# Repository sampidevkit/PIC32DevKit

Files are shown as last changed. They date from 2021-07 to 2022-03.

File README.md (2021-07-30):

# PIC32MM MICROCONTROLLER DEVELOPMENT KIT
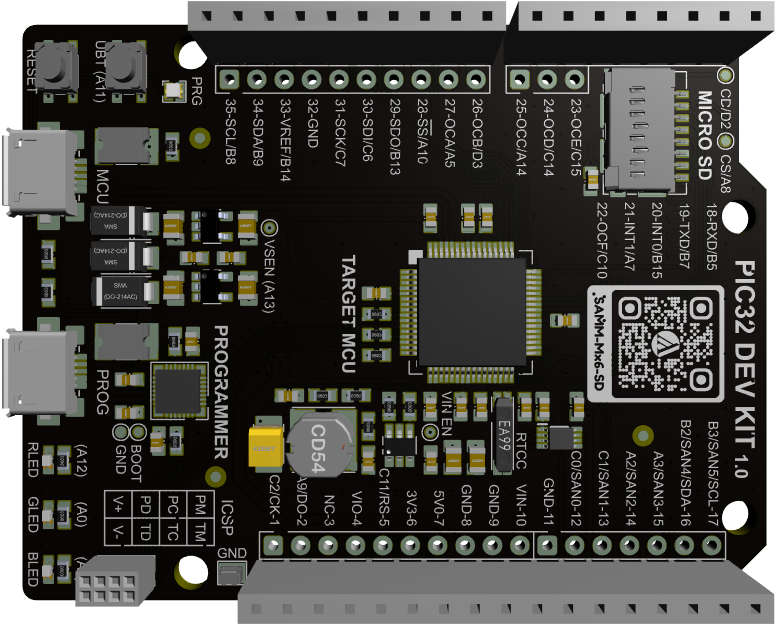
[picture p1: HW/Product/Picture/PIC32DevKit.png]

<br/>Đây là thiết kế mở - một kit phát triển vi điều khiển 32-bit họ PIC32MM. Kit được trang bị các tính năng như sau:<br/>
* PCB và các ngõ vào ra theo định dạng của Arduino Uno.
* Mạch nạp tích hợp theo kiểu USB lưu trữ, tệp hex sẽ được kéo - thả để nạp trực tiếp mà không cần sử dụng phần mềm nạp cũng như các mạch nạp bên ngoài như PICKit, ICD, ..., tuy nhiên người dùng vẫn có thể sử dụng được các mạch nạp chuyên dụng kết nối với cổng ICSP được thiết kế sẵn.
* Cổng chuyển đổi USB - UART, người dùng không cần sử dụng thêm thiết bị chuyển đổi bên ngoài như CP2102, FT232, ...
* Khe cắm thẻ nhớ. Giao tiếp SPI với MCU chính.
* Bộ chuyển đổi logic để giao tiếp với RGB chip LED (APA102, WS2812, SK9822, ...). <br/>
## 1. Sơ Đồ Khối
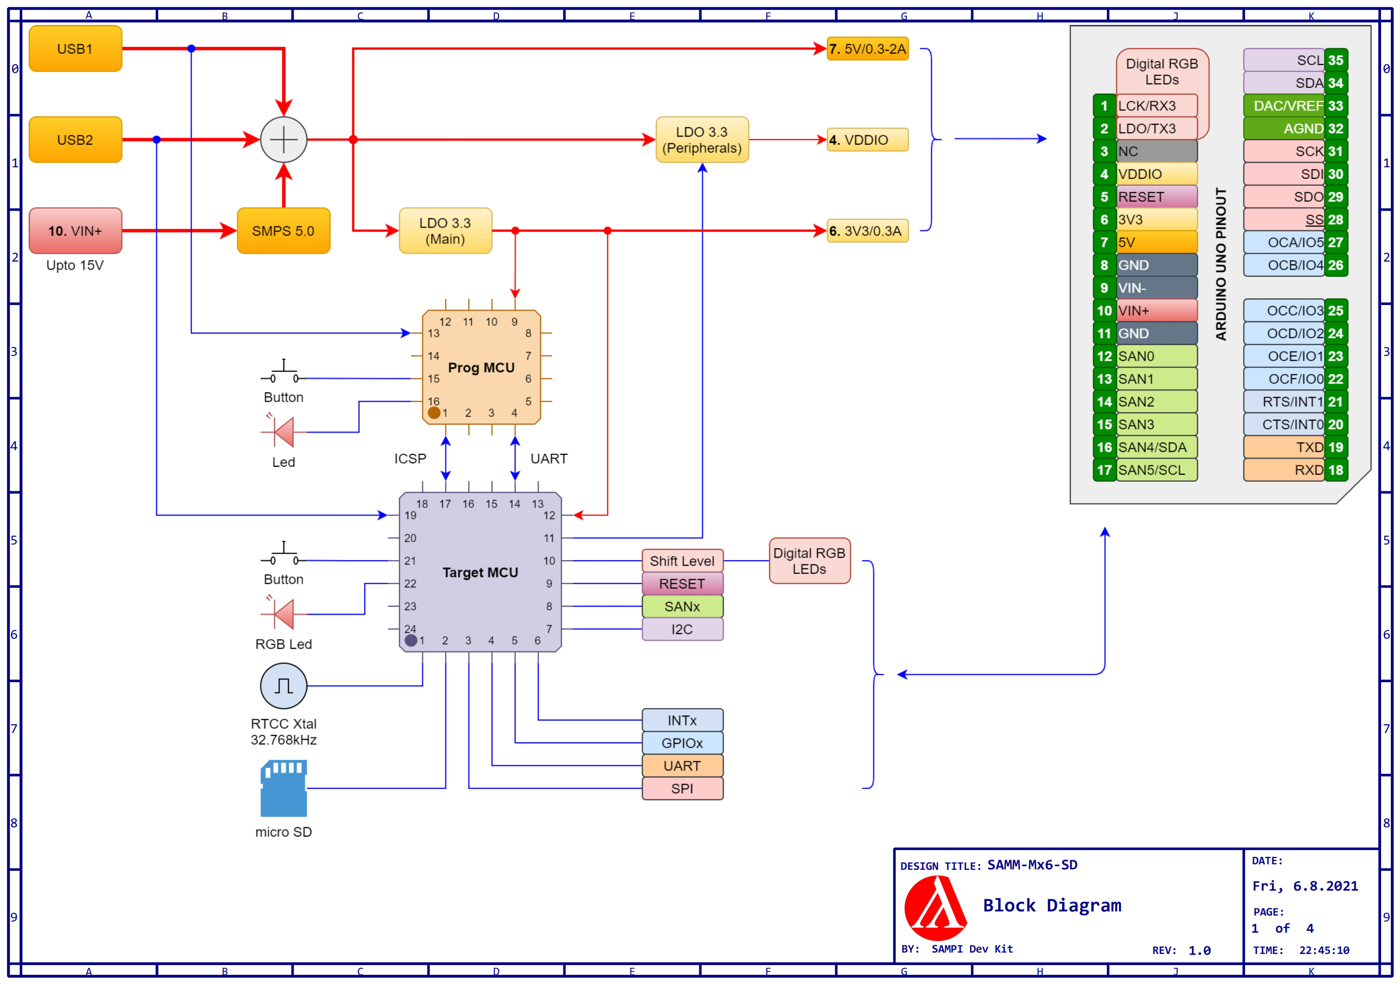
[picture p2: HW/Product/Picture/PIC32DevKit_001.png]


## 2. Sơ Đồ Nguyên Lý
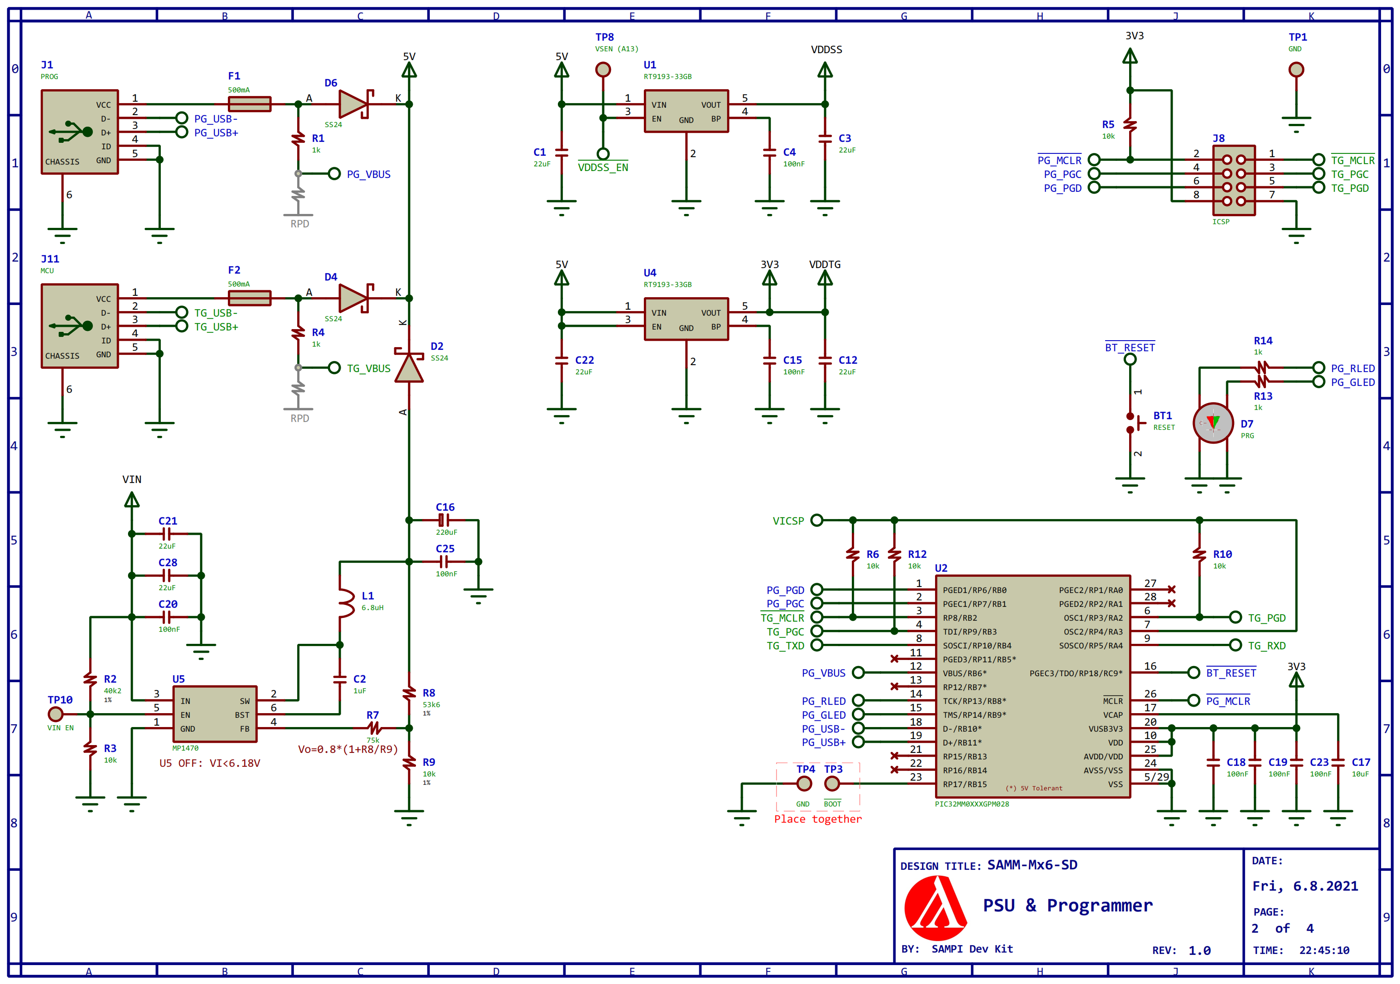
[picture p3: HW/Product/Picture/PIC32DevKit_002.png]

<br/>
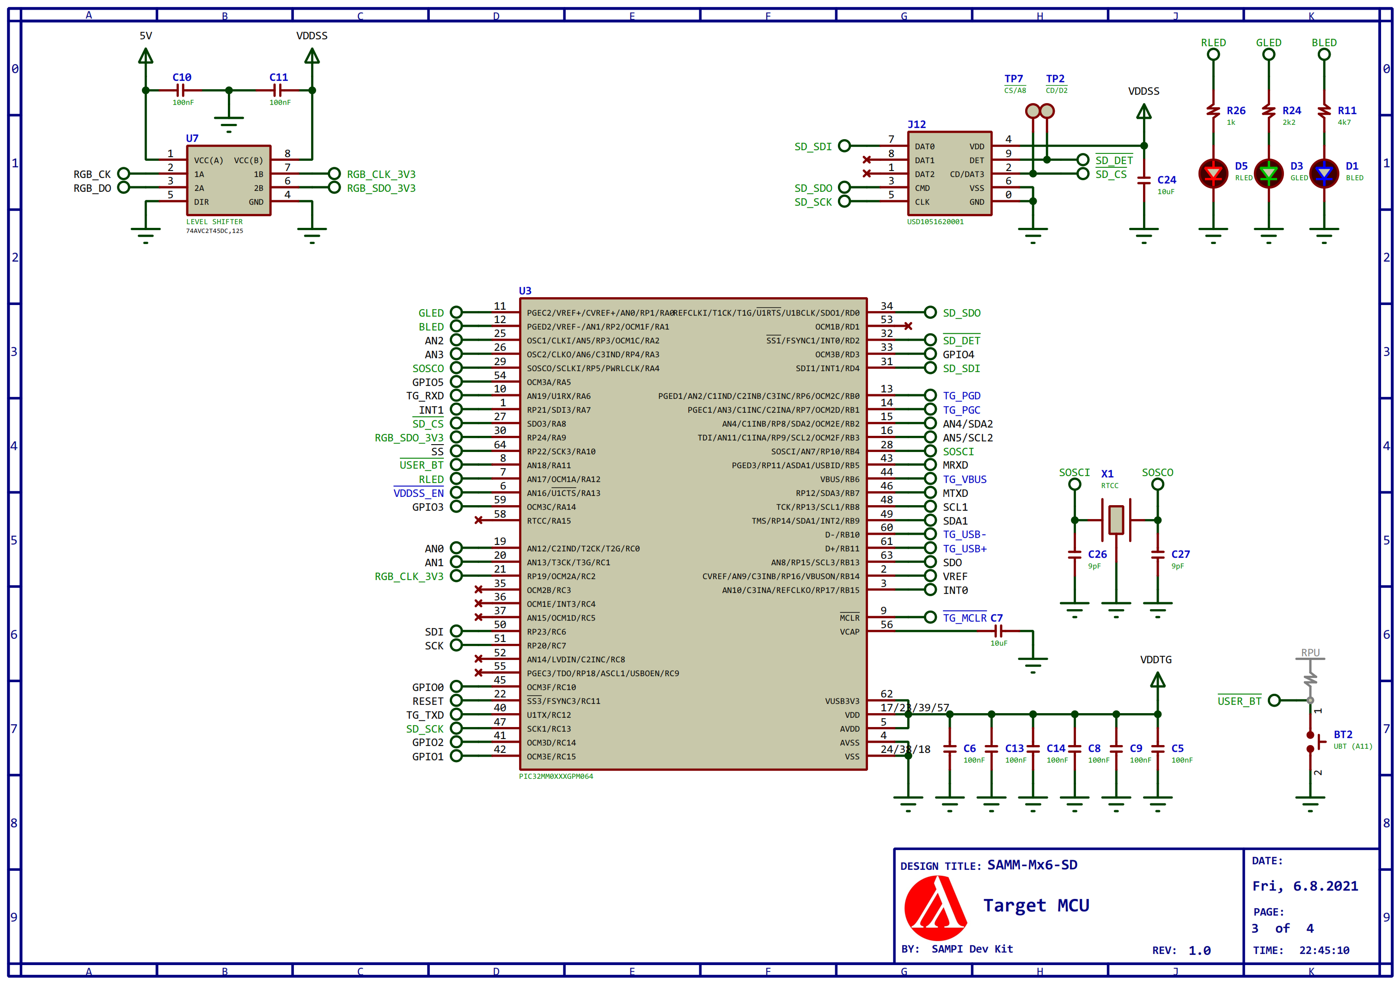
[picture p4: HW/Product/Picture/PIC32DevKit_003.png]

<br/>
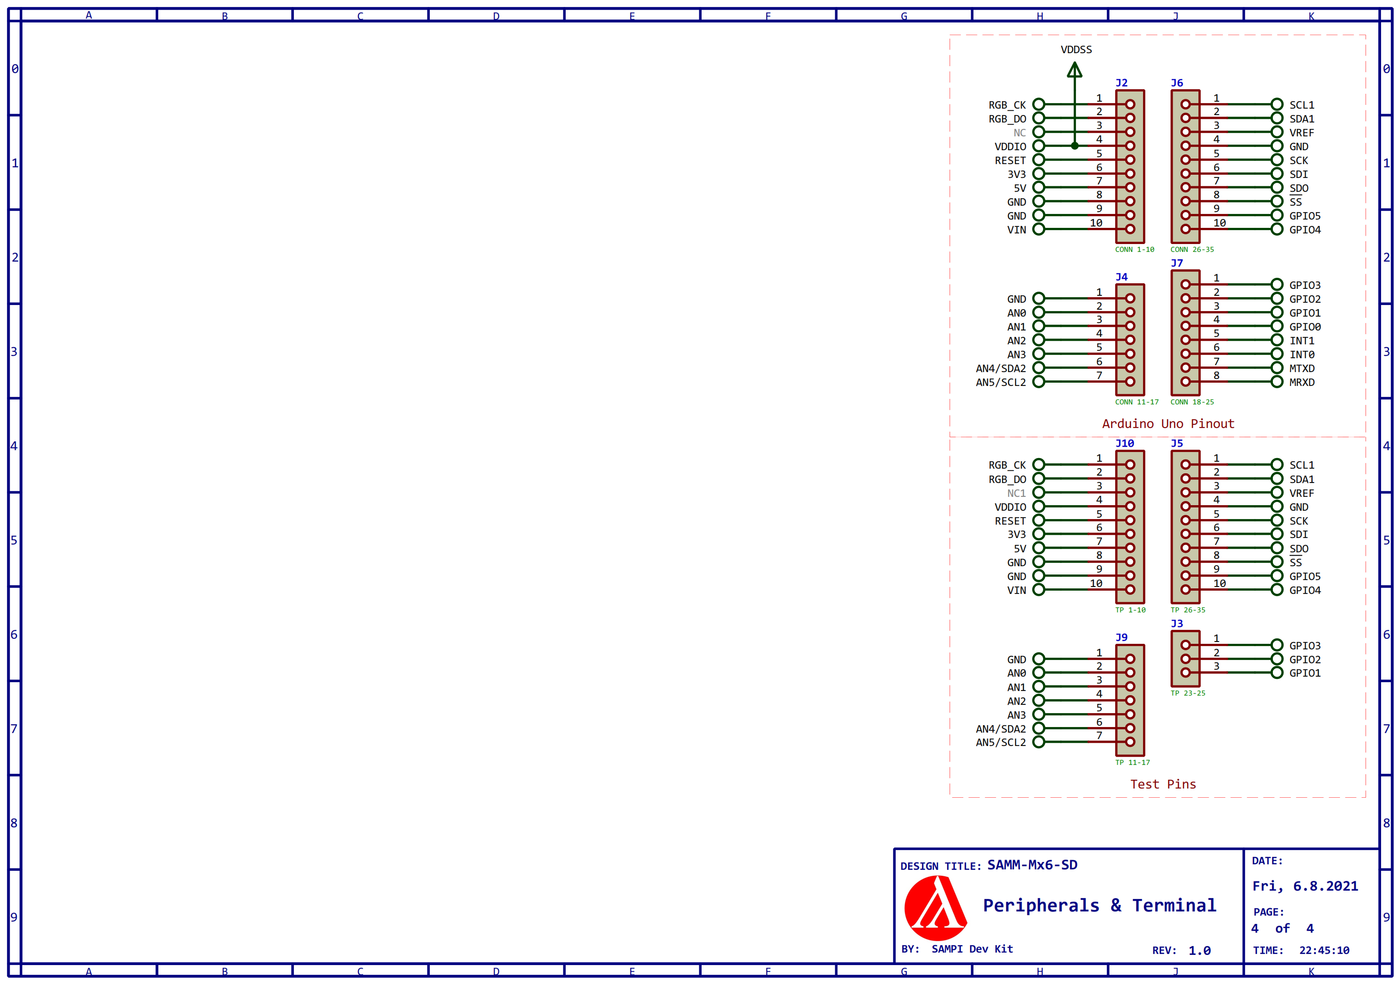
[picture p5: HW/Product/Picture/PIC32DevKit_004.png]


## 3. Vi Điều Khiển Chính PIC32MM0XXXGPM064
Họ vi điều khiển PIC32MM là họ vi điều khiển 32-bit sử dụng core MIPS microAptiv.<br/>
* Dao động nội 8MHz, 32kHz, PLL 96MHz. Tốc độ tối đa 37 DMIPS/25MHz.
* Bộ nhớ chương trình từ 64kByte đến 256kByte, RAM 16byte-32byte.
* Chip được trang bị 3x UART, 3x SPI, 3x I2C, 1x USB OTG.
* PWM chuyên dụng để điều khiển động cơ, 3x timer 16bit hoặc 1x timer 16bit + 1 timer 32bit.
* ADC 10/12 bit, 3x compare.
* Tích hợp module thời gian thực RTCC.
* Ngõ vào ra của các module chức năng có thể cấu hình nhờ chức năng Peripheral Pin Select (PPS).
* Năng lượng thấp, phù hợp cho các ứng dụng sử dụng pin.<br/>
* [Thông tin thêm xem tại đây](https://www.microchip.com/en-us/product/PIC32MM0256GPM064).

## 4. Môi Trường Lập Trình, Trình Biên Dịch và Công Cụ Hỗ Trợ

### 4.1. Môi Trường Lập Trình MPLAB X IDE

Môi trường lập trình MPLAB X IDE sử dụng mã nguồn của Netbeans, giao diện thân thiện và dễ sử dụng. Tải về và hướng dẫn cài đặt tại đây: [Installing MPLAB® X IDE](https://microchipdeveloper.com/mplabx:installation). </br>
Khuyến cáo: Sử dụng Windows 64bit với RAM tối thiểu 4GB và ổ cứng trống từ 20GB.

### 4.2. Trình Biên Dịch MPLAB XC32
Nếu sử dụng ngôn ngữ lập trình C để lập trình cho Kit, bạn cần tải về trình biên dịch XC32. Nó sẽ chuyển mã C thành mã assembly. </br>

</br>Sau đó, nó sẽ chuyển mã assembly sang mã máy dưới dạng file HEX. Bạn cũng có thể sử dụng XC32 để biên dịch cho mã nguồn được viết trực tiếp bằng assembly. 

</br>Trình biên dịch có thể sử dụng miễn phí, không giới hạn code size, chỉ giới hạn các cấp độ tối ưu mã nguồn. Chức năng tối ưu mã nguồn sử dụng trong sản xuất, không cần thiết trong học tập. Tải về và hướng dẫn cài đặt tại đây: [Installing MPLAB® XC32 Compiler](https://microchipdeveloper.com/xc32:installation).

### 4.3. Công Cụ Cấu Hình và Tạo Code Mẫu MPLAB Code Configurator (MCC)
MCC là một plugin của MPLAB X IDE, hỗ trợ tạo cấu hình chip, cấu hình các ngoại vi và các API để người dùng sử dụng mà không mất nhiều thời gian xây dựng chúng. </br>

</br>Tải về và hướng dẫn cài đặt tại đây: [Install MPLAB® Code Configurator (MCC)](https://microchipdeveloper.com/install:mcc).

## 5. Mạch Nạp Tích Hợp

### 5.1. Nạp Chương Trình Mạch Nạp
Chương trình mạch nạp chỉ cần nạp 1 lần. Các công cụ cần chuẩn bị: </br>
* Mạch nạp chuyên dụng như PICkit3, PICkit4, Snap, ICD3, ICD4, ...
* Header đực 2x4x1.27 dùng cho cổng nạp ICSP theo sơ đồ sau: </br>
* Đang cập nhật ...

### 5.2. Cập Nhật Chương Trình Mạch Nạp
Để cập nhật chương trình mới cho chip nạp, bạn có thể thực hiện như mục 5.1 hoặc thực hiện như sau: </br>
* Kết nối kit với máy tính bằng cáp micro USB.
* Nhấn giữ nút RESET đến khi các đèn STT, RLED, BLED cùng sáng (khoảng 5s).
* Vào My Computer/ This PC sẽ thấy xuất hiện ổ đĩa BOOTLOADER.
* Đang cập nhật ...

### 5.3 Các Trạng Thái LED Lỗi
* Lỗi khi ghi file hex vào ổ đĩa của kit: File nạp không đúng định dạng hoặc sự cố kết nối USB.
* Đang cập nhật ...

## 6. Hướng Dẫn Lập Trình Cơ Bản
Đang cập nhật ...

## 7. Tài Liệu Kỹ Thuật:
Đang cập nhật ...

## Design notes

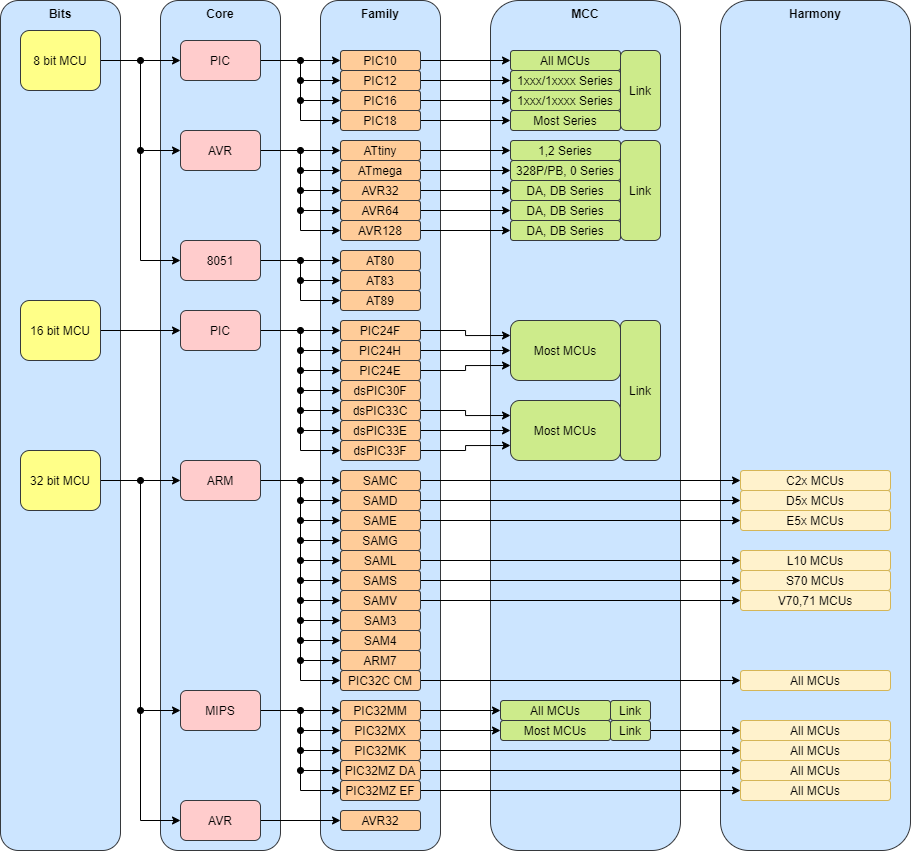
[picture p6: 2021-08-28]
Docs/MICROCHIP_MCU_Overview.png

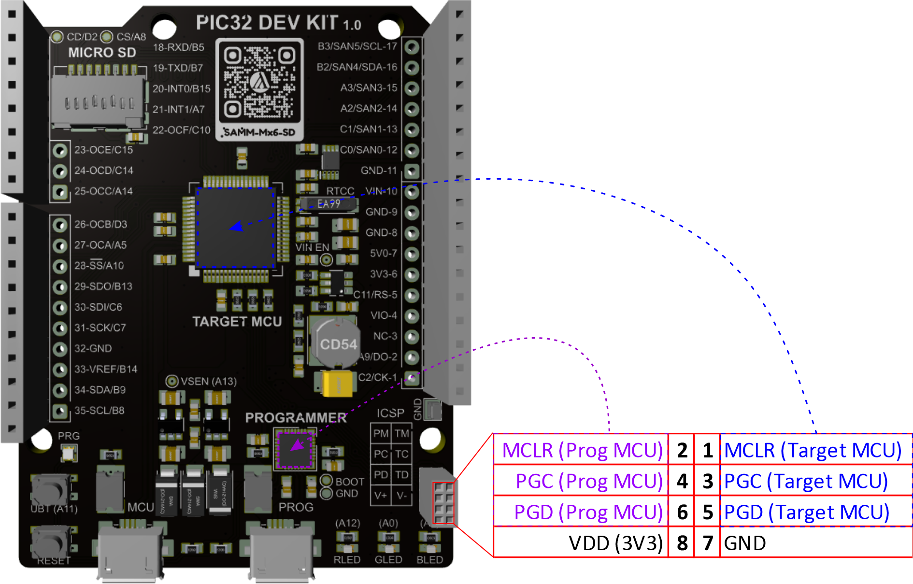
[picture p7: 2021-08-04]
Docs/ICSP.png

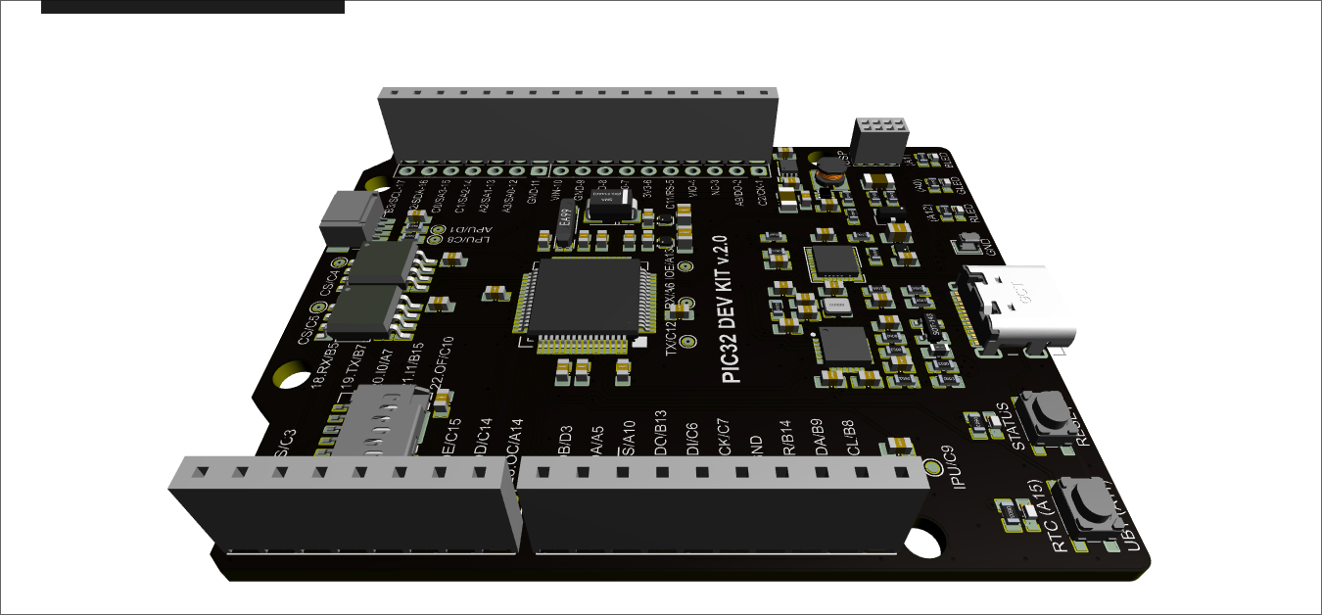
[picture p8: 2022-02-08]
HW/Product/V2.0/Picture/ScreenShot_20220208212421.png

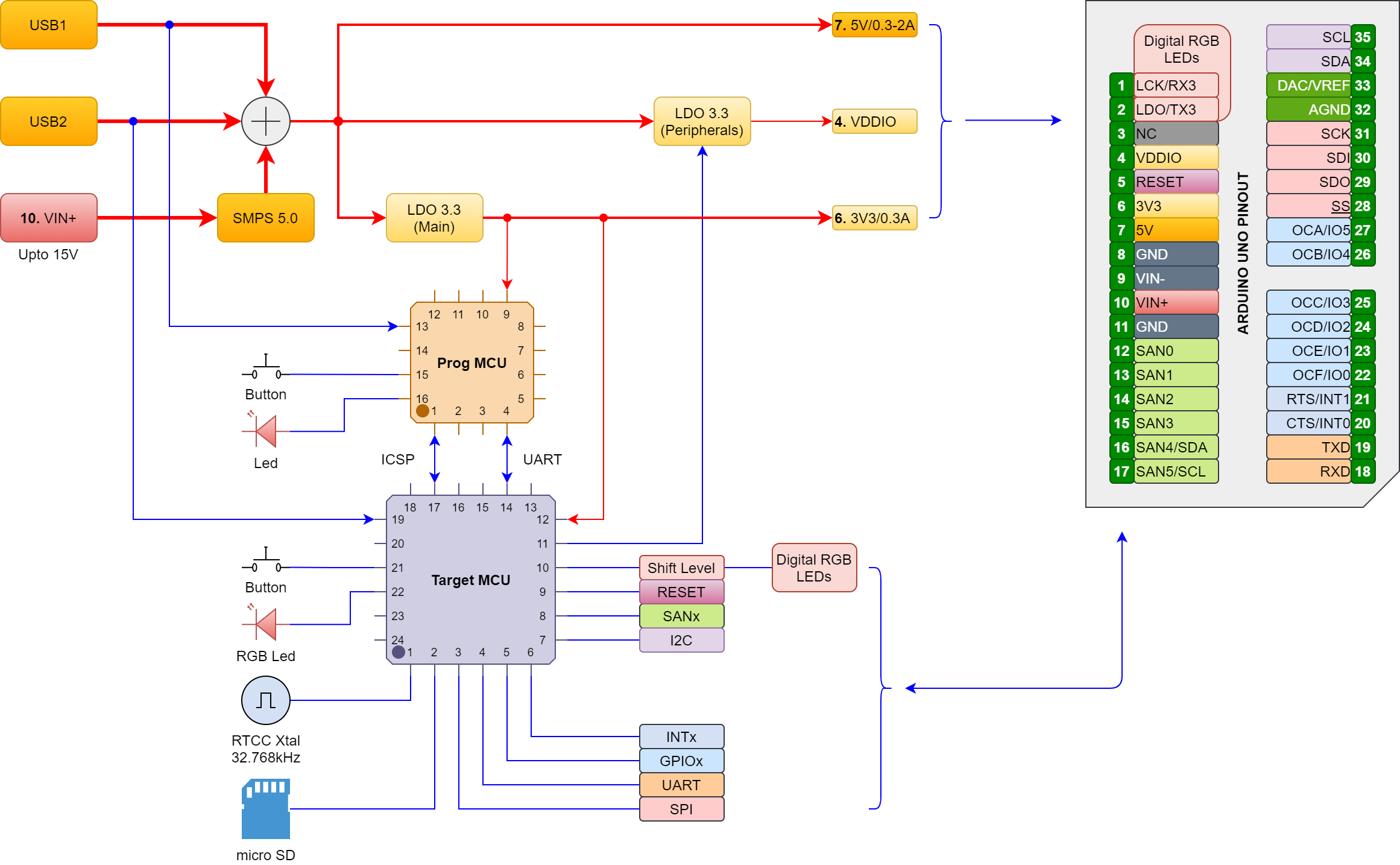
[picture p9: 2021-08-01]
Docs/Diagram.png

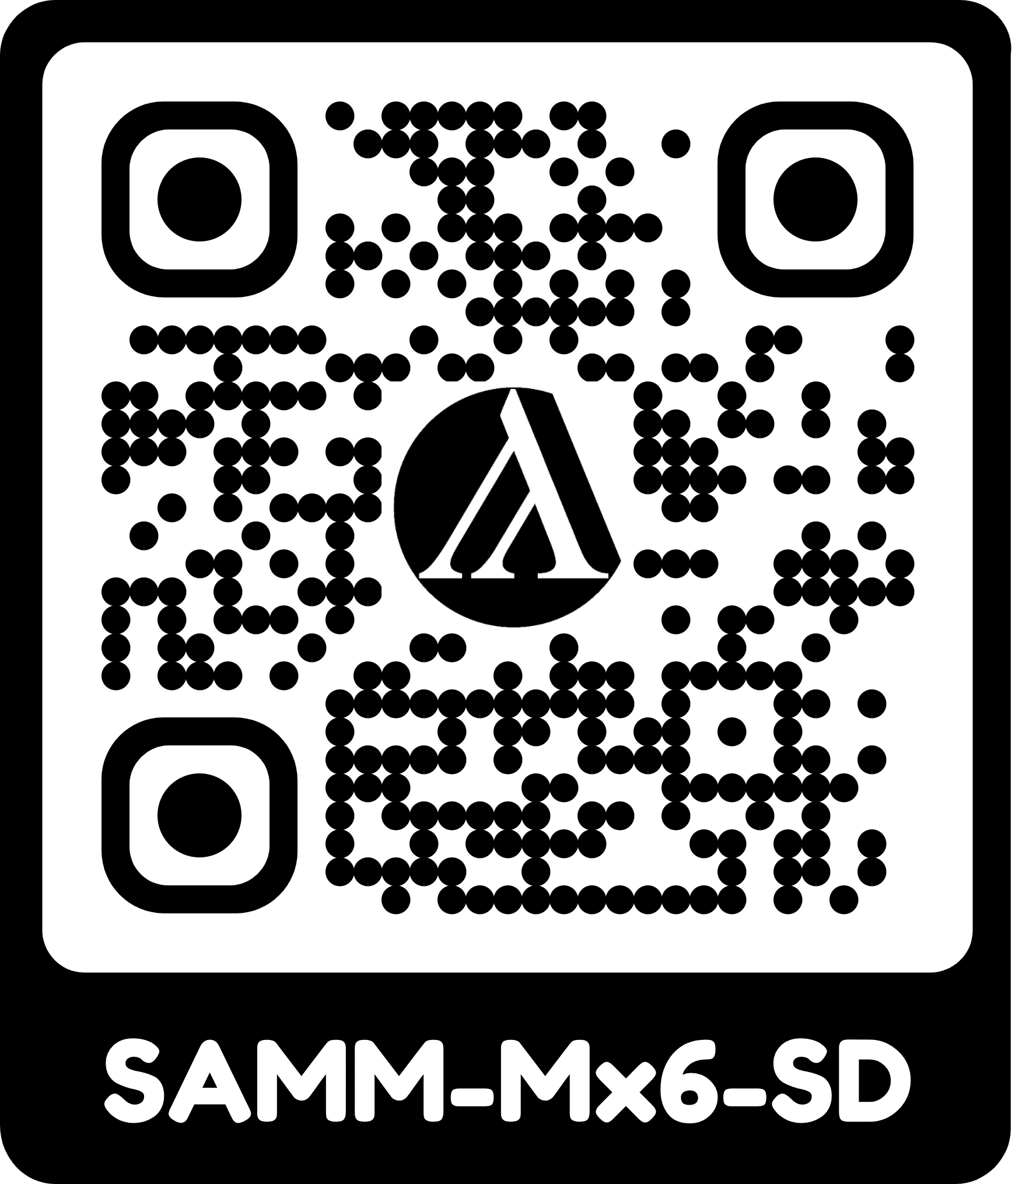
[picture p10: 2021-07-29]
Docs/bit.ly_2TLaNEk.png

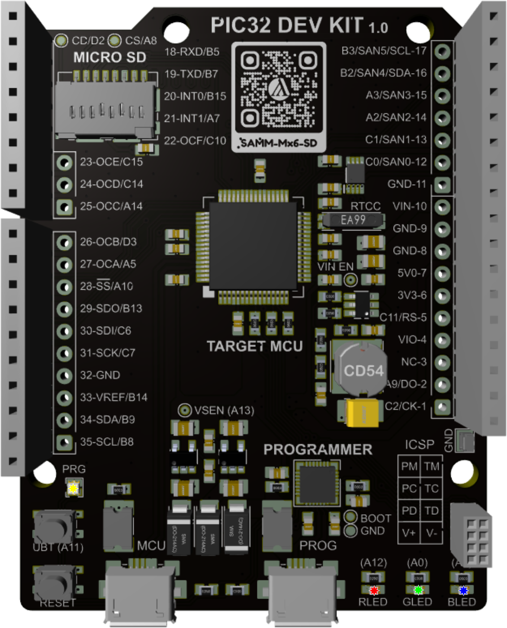
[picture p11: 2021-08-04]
Docs/SAMM-Mx6-SD.png

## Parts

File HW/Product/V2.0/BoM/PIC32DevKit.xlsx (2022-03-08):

No | Part Number | Manufacture | Description | Stock Link | References | Quantity | Unit Cost | Sub Cost
1 | CL10A106MQ8NNNC | Samsung | CAP CER 10UF 6.3V X5R 0603 | https://www.thegioiic.com/products/tu-gom-0603-10uf-25v | C1, C7, C17, C20, C22, C24, C29, C38 | 8 | VND 880 | VND 7040
2 | CL10B104KB8NNWC | Samsung | CAP CER 0.1UF 50V X7R 0603 | https://www.thegioiic.com/products/tu-gom-0603-100nf-0-1uf-50v | C2, C3, C5, C6, C8, C9, C10, C11, C13, C14, C18, C19, C23, C25, C28, C30, C31, C32, C35, C36, C37 | 21 | VND 207 | VND 4347
3 | CL31A226MOCLNNC | Samsung | CAP CER 22UF 16V X5R 1206 | https://www.thegioiic.com/products/tu-gom-0805-22uf-16v | C4, C21 | 2 | VND 1120 | VND 2240
4 | CL21A226MQQNNNG | Samsung | CAP CER 22UF 6.3V X5R 0805 | https://www.thegioiic.com/products/tu-gom-0805-22uf-16v | C12, C15, C16 | 3 | VND 1120 | VND 3360
5 | 0603N100J500CT | Walsin | CAP CER 10PF 50V C0G/NP0 0603 | https://www.thegioiic.com/products/tu-gom-0603-10pf-50v | C26, C27, C33, C34 | 4 | VND 207 | VND 828
6 | RC0603FR-075K1L | Yageo | RES 5.1K OHM 1% 1/10W 0603 | https://www.thegioiic.com/products/dien-tro-51-kohm-0603-1 | R1, R8, R16, R22 | 4 |  | VND 0
7 | RC0603JR-131KL | Yageo | RES 1K OHM 5% 1/10W 0603 | https://www.thegioiic.com/products/dien-tro-1-kohm-0603-5 | R2, R13, R26 | 3 |  | VND 0
8 | RC0603FR-0753K6L | Yageo | RES 53.6K OHM 1% 1/10W 0603 | https://www.thegioiic.com/products/dien-tro-53-6-kohm-0603-1 | R3, R15 | 2 |  | VND 0
9 | AC0603FR-0710KL | Yageo | RES 10K OHM 1% 1/10W 0603 | https://www.thegioiic.com/products/dien-tro-10-kohm-0603-1- | R4, R5, R6, R9, R10, R12, R18, R19, R20, R21 | 10 |  | VND 0
10 | RC0603JR-072K2L | Yageo | RES 2.2K OHM 5% 1/10W 0603 | https://www.thegioiic.com/products/dien-tro-2-2-kohm-0603-5 | R7, R14, R23, R24, R25 | 5 |  | VND 0
11 | RC0603JR-074K7L | Yageo | RES 4.7K OHM 5% 1/10W 060 | https://www.thegioiic.com/products/dien-tro-4-7-kohm-0603-5 | R11 | 1 |  | VND 0
13 | RC0603FR-0712KL | Yageo | RES 12K OHM 1% 1/10W 0603 | https://www.thegioiic.com/products/dien-tro-12-kohm-0603-1- | R17 | 1 |  | VND 0
14 | AP62201Z6-7 | Diodes | DCDC CONV HV BUCK SOT563 T&R 3K | https://www.digikey.com/en/products/detail/diodes-incorporated/AP62201Z6-7/13161377 | U1 | 1 |  | VND 0
15 | PIC32MM0064GPM028-I/M6 | Microchip | IC MCU 32BIT 64KB FLASH 28UQFN | https://www.digikey.com/en/products/detail/microchip-technology/PIC32MM0064GPM028-I-M6/8037777 | U2 | 1 |  | VND 0
16 | PIC32MM0256GPM064T-I/PT | Microchip | IC MCU 32BIT 256KB FLASH 64TQFP | https://www.digikey.com/en/products/detail/microchip-technology/PIC32MM0256GPM064T-I-PT/7354645 | U3 | 1 |  | VND 0
17 | DRTR5V0U2SR-7 | Diodes | TVS DIODE 5.5VWM SOT143 | https://www.digikey.com/en/products/detail/diodes-incorporated/DRTR5V0U2SR-7/4402528 | U4 | 1 |  | VND 0
18 | MIC5528-3.3YMX-TR | Microchip | IC REG LINEAR 3.3V 500MA 6XTDFN | https://www.digikey.com/en/products/detail/microchip-technology/MIC5528-3-3YMX-TR/4465358 | U5, U8, U9 | 3 |  | VND 0
19 | USB2422/MJ | Microchip | IC HUB CTLR USB 2.0 24QFN | https://www.digikey.com/en/products/detail/microchip-technology/USB2422-MJ/4080182 | U6 | 1 |  | VND 0
20 | 74AVC2T45DC,125 | Nexperia | IC TRNSLTR BIDIRECTIONAL 8VSSOP | https://www.digikey.com/en/products/detail/nexperia-usa-inc/74AVC2T45DC-125/1692558 | U7 | 1 |  | VND 0
21 | SST25PF080B-80-4C-SAE-T | Microchip | IC FLASH 8MBIT SPI 80MHZ 8SOIC | https://www.digikey.com/en/products/detail/microchip-technology/SST25PF080B-80-4C-SAE-T/3908714 | U10 | 1 |  | VND 0
22 | 25AA160D-I/SN | Microchip | IC EEPROM 16KBIT SPI 10MHZ 8SOIC | https://www.digikey.com/en/products/detail/microchip-technology/25AA160D-I-SN/2125494 | U11 | 1 |  | VND 0
23 | RZF013P01TL | Microchip | MOSFET P-CH 12V 1.3A TUMT3 | https://www.digikey.com/en/products/detail/rohm-semiconductor/RZF013P01TL/5042831 | Q1 | 1 |  | VND 0
24 |  |  | SML-D12U8W, BLED |  | D1 | 1 |  | VND 0
25 |  |  | SML-D12U8W, RTC (A15) |  | D2, D5 | 2 |  | VND 0
26 |  |  | SML-D12U8W, GLED |  | D3 | 1 |  | VND 0
27 |  |  | SML-D12U8W, STATUS |  | D4 | 1 |  | VND 0
28 |  |  | DO214AC, SS24 |  | D6 | 1 |  | VND 0
29 |  |  | PTS815, RESET |  | BT1, BT2 | 2 |  | VND 0
30 |  |  | 0603_FE, 100R@100MHz |  | FT1 | 1 |  | VND 0
31 |  |  | GCT_USB4105, USB2 |  | J1 | 1 |  | VND 0
32 |  |  | CONN-SIL10, CONN 1-10 |  | J2, J6 | 2 |  | VND 0
33 |  |  | CONN-SIL7, CONN 11-17 |  | J4 | 1 |  | VND 0
34 |  |  | CONN-SIL8, CONN 18-25 |  | J7 | 1 |  | VND 0
35 |  |  | ISP8, ICSP |  | J8 | 1 |  | VND 0
36 |  |  | QWIIC, Qwiic |  | J11 | 1 |  | VND 0
37 |  |  | USD1051620001, USD1051620001 |  | J12 | 1 |  | VND 0
38 |  |  | IND_CD32, 4.7uH |  | L1 | 1 |  | VND 0
39 |  |  | SMD4_7015, RTCC |  | X1 | 1 |  | VND 0
40 |  |  | SMD4_2.5X2.0, 24MHz |  | X2 | 1 |  | VND 0
 |  |  |  |  |  | 96 | VND 185.5729167 | VND 17815

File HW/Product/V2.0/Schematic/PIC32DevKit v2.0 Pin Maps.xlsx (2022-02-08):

Pin | Port | Post | Name | Function | Direction | Init State
1 | A | 7 | INT0 | EXT_INT4 | INPUT | PULL UP
6 | A | 13 | VDDSS_EN | GPIO | OUTPUT | LOW
7 | A | 12 | RLED | GPIO | OUTPUT | LOW
8 | A | 11 | USER_BT_N | GPIO | INPUT | PULL UP
10 | A | 6 | TG_RXD | U1RX | INPUT | PULL UP
11 | A | 0 | GLED | GPIO | OUTPUT | LOW
12 | A | 1 | BLED | GPIO | OUTPUT | LOW
25 | A | 2 | AN1 | AN5 | INPUT | ANALOG
26 | A | 3 | AN0 | AN6 | INPUT | ANALOG
27 | A | 8 | RA8 | RFU | X | X
29 | A | 4 | SOSCO | SOSCO | OUTPUT | LOW
30 | A | 9 | RGB_SDO_3V3 | CLC2OUT | OUTPUT | LOW
54 | A | 5 | GPIO5/OA | OCM3A | OUTPUT | LOW
58 | A | 15 | RTCC_LED | RTCC | OUTPUT | LOW
59 | A | 14 | GPIO3/OC | OCM3C | OUTPUT | LOW
64 | A | 10 | SS_N | GPIO | OUTPUT | HIGH
2 | B | 14 | VREF | CVREF | OUTPUT | ANALOG
3 | B | 15 | INT1 | IOC | INPUT | PULL UP
13 | B | 0 | TG_PGD | GPIO | INPUT | PULL UP
14 | B | 1 | TG_PGC | GPIO | INPUT | PULL UP
15 | B | 2 | AN4/SDA2 | SDA2 | INPUT | LOW
16 | B | 3 | AN5/SCL2 | SCL2 | INPUT | LOW
28 | B | 4 | SOSCI | SOSCI | INPUT | LOW
43 | B | 5 | MRXD | U2RX | INPUT | PULL UP
44 | B | 6 | TG_VBUS | VBUS | INPUT | PULL DOWN
46 | B | 7 | MTXD | U2TX | OUTPUT | HIGH
48 | B | 8 | SCL1 | SCL1 | INPUT | LOW
49 | B | 9 | SDA1 | SDA1 | INPUT | LOW
60 | B | 10 | TG_USB- | D- | INPUT | LOW
61 | B | 11 | TG_USB+ | D+ | INPUT | LOW
63 | B | 13 | SDO | SDO2 | OUTPUT | LOW
19 | C | 0 | AN3 | AN12 | INPUT | ANALOG
20 | C | 1 | AN2 | AN13 | INPUT | ANALOG
21 | C | 2 | RGB_CLK_3V3 | CLC1OUT | OUTPUT | LOW
22 | C | 11 | RESET | GPIO | OUTPUT | LOW
35 | C | 3 | EE_CS_N | GPIO | OUTPUT | HIGH
36 | C | 4 | FL_CS_N | GPIO | OUTPUT | HIGH
37 | C | 5 | SD_CS_N | GPIO | OUTPUT | HIGH
40 | C | 12 | TG_TXD | U1TX | OUTPUT | HIGH
41 | C | 14 | GPIO2/OD | OCM3D | OUTPUT | LOW
42 | C | 15 | GPIO1/OE | OCM3E | OUTPUT | LOW
45 | C | 10 | GPIO0/OF | OCM3F | OUTPUT | LOW
47 | C | 13 | MEM_SCK | SCK1 | OUTPUT | LOW
50 | C | 6 | SDI | SDI2 | INPUT | LOW
51 | C | 7 | SCK | SCK2 | OUTPUT | LOW
52 | C | 8 | LPU_C8 | GPIO | OUTPUT | LOW
55 | C | 9 | IPU_C9 | GPIO | OUTPUT | LOW
31 | D | 4 | MEM_SDI | SDI1 | INPUT | LOW
32 | D | 2 | SD_DET_N | GPIO | INPUT | PULLUP
33 | D | 3 | GPIO4/OB | OCM3B | OUTPUT | LOW
34 | D | 0 | MEM_SDO | SDO1 | OUTPUT | LOW
53 | D | 1 | APU_D1 | GPIO | OUTPUT | LOW
4 | P | P | AVSS | GND | X | X
5 | P | P | AVDD | 3V3 | X | X
9 | P | P | MCLR_N | MCLR | X | X
17 | P | P | VDD | 3V3 | X | X
18 | P | P | VSS | GND | X | X
23 | P | P | VDD | 3V3 | X | X
24 | P | P | VSS | GND | X | X
38 | P | P | VSS | GND | X | X
39 | P | P | VDD | 3V3 | X | X
56 | P | P | VCAP | VCAP | X | X
57 | P | P | VDD | 3V3 | X | X
62 | P | P | VUSB3V3 | 3V3 | X | X

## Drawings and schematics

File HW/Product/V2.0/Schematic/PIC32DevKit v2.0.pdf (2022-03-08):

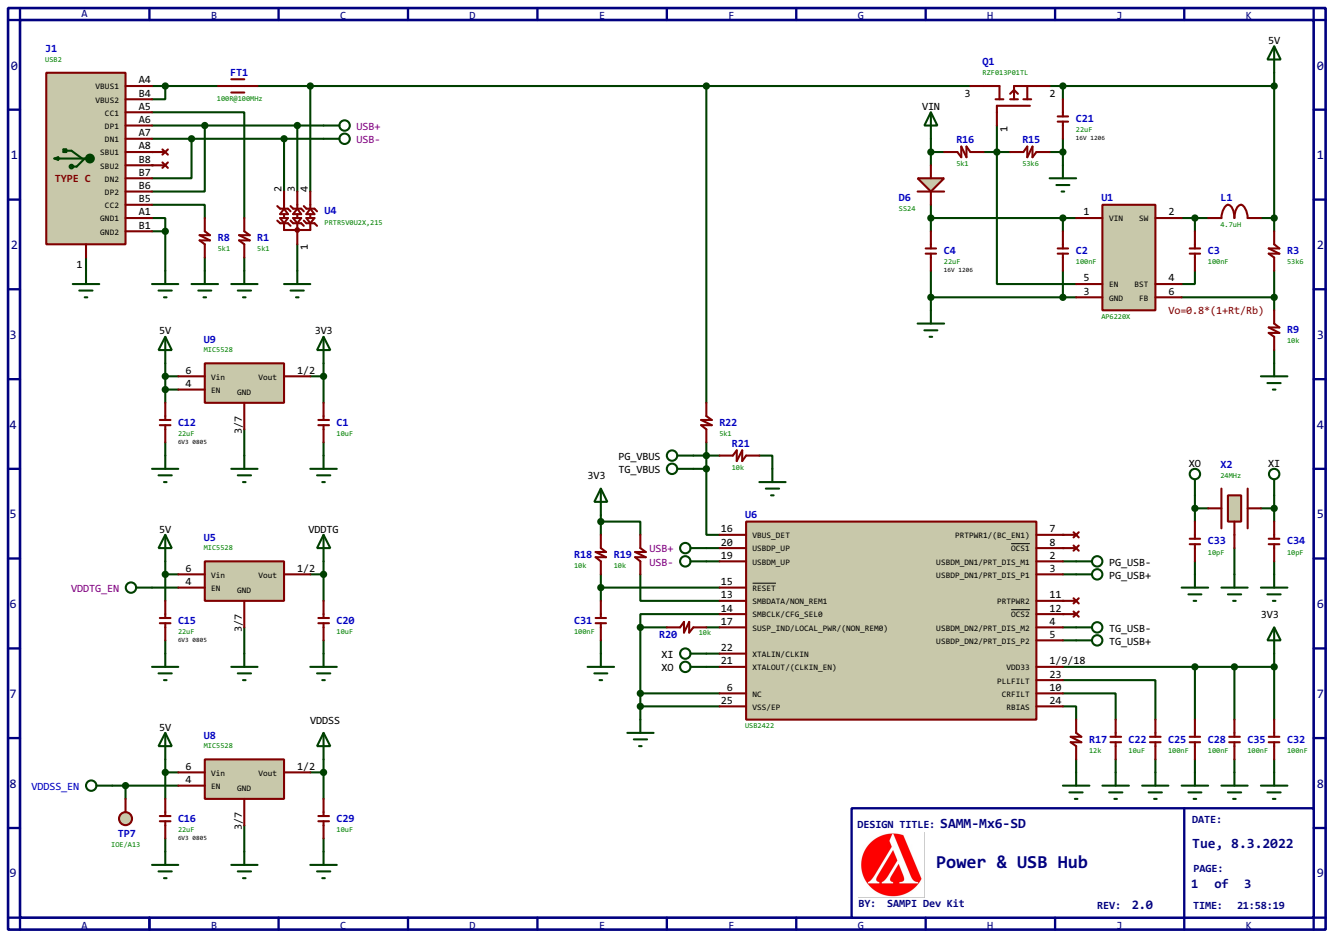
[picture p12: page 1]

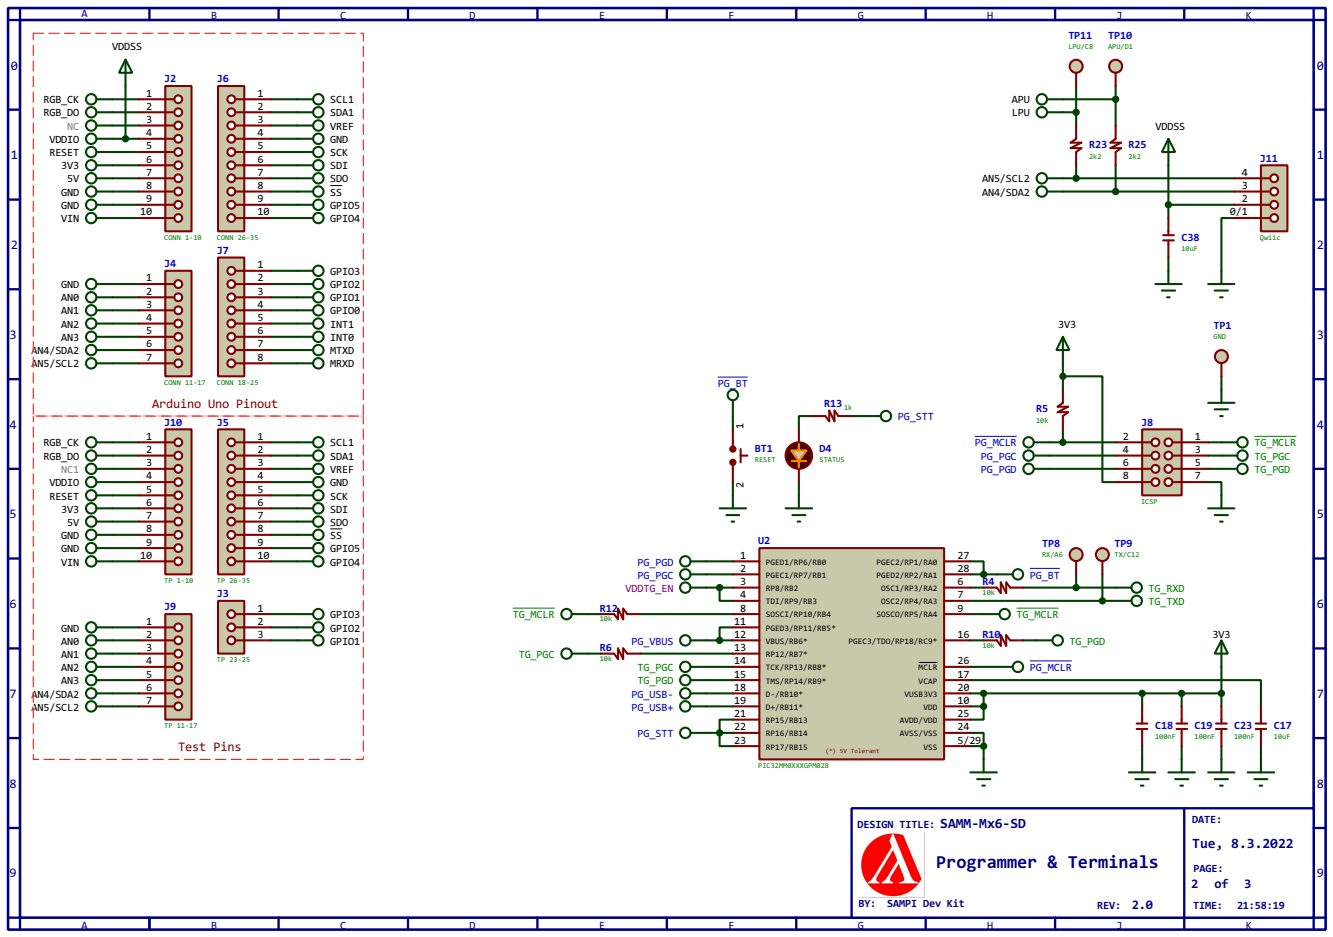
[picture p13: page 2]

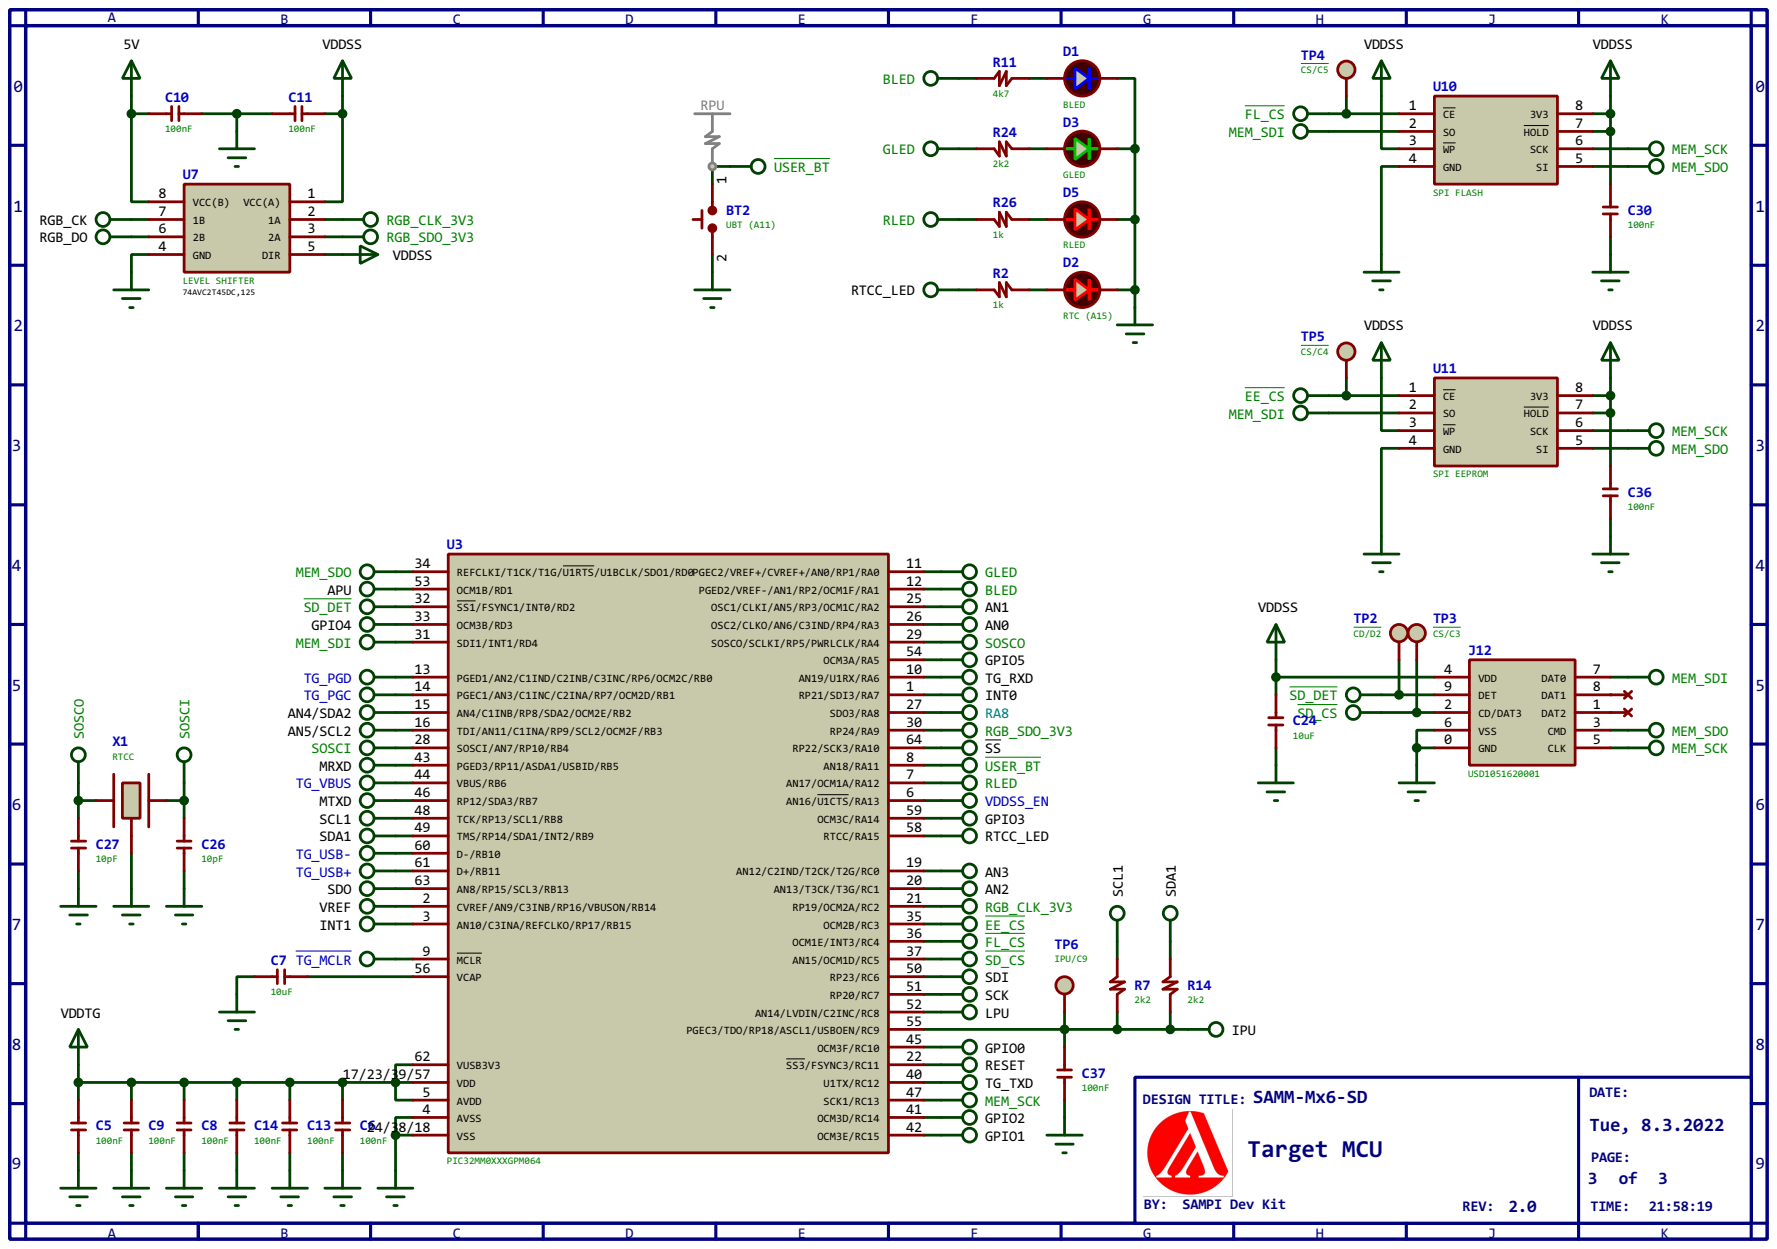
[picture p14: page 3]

VDD 17/23/39/57

AVDD 5

DESIGN TITLE: SAMM-Mx6-SD

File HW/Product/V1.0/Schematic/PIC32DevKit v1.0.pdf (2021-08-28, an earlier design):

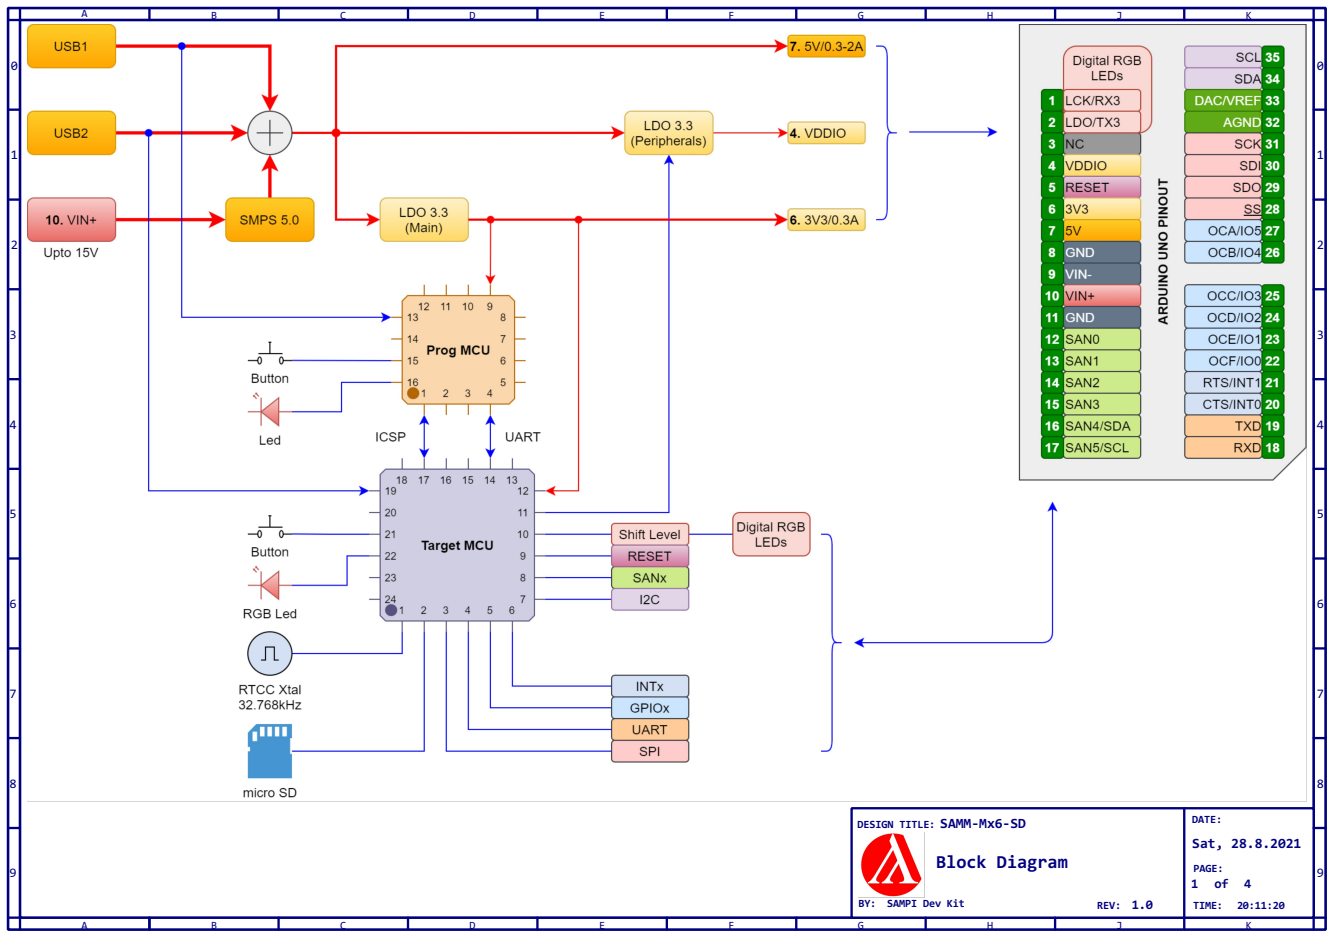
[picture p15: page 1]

DESIGN TITLE: SAMM-Mx6-SD

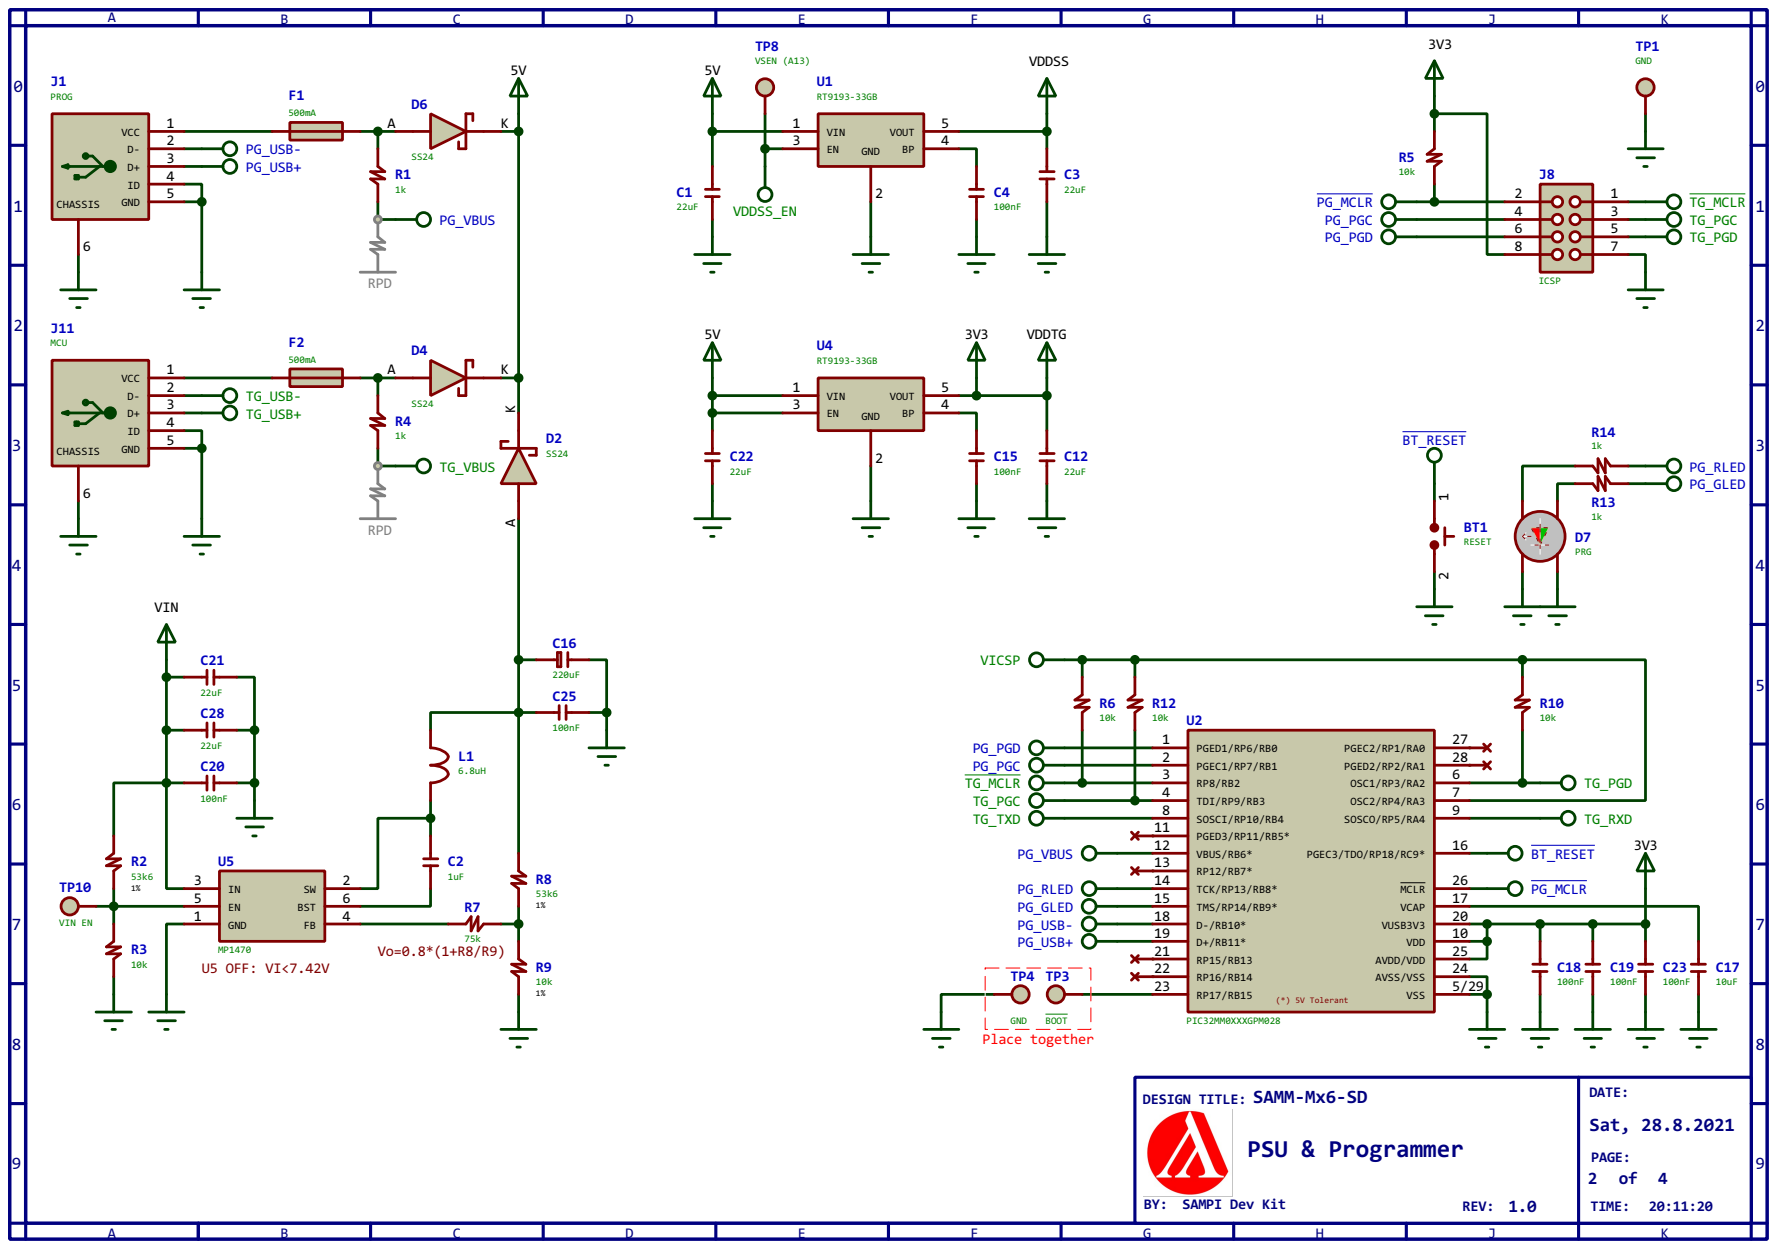
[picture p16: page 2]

DESIGN TITLE: SAMM-Mx6-SD

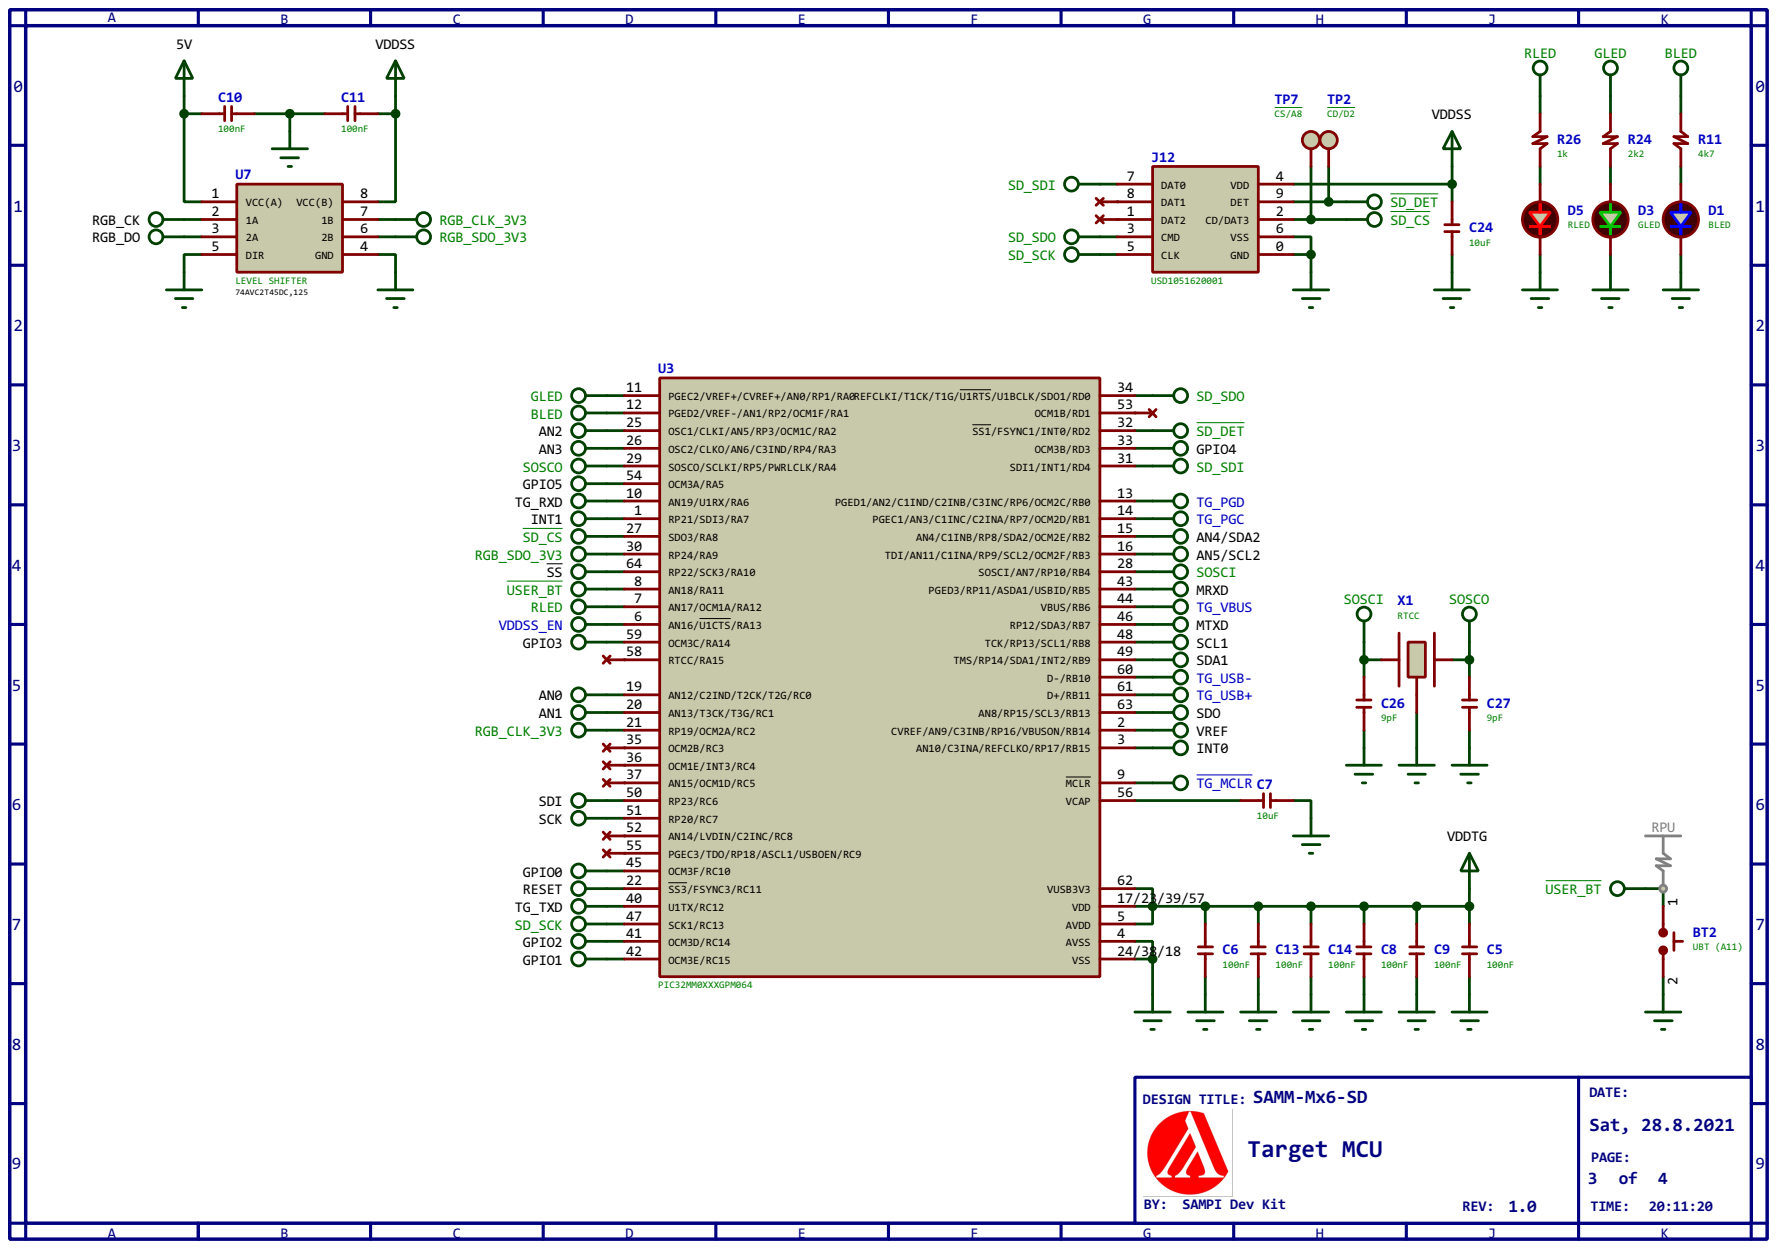
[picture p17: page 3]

DESIGN TITLE: SAMM-Mx6-SD

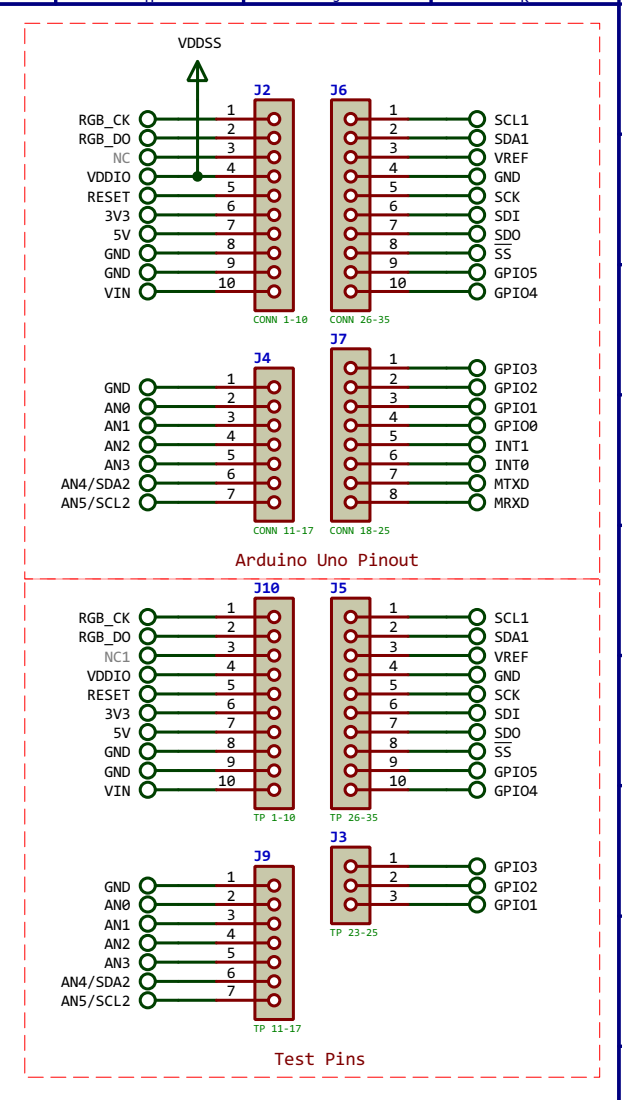
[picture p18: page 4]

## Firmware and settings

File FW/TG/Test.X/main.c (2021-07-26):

/**
  Generated main.c file from MPLAB Code Configurator

  @Company
    Microchip Technology Inc.

  @File Name
    main.c

  @Summary
    This is the generated main.c using PIC24 / dsPIC33 / PIC32MM MCUs.

  @Description
    This source file provides main entry point for system initialization and application code development.
    Generation Information :
        Product Revision  :  PIC24 / dsPIC33 / PIC32MM MCUs - 1.170.0
        Device            :  PIC32MM0256GPM064
    The generated drivers are tested against the following:
        Compiler          :  XC16 v1.61
        MPLAB 	          :  MPLAB X v5.45
*/

/*
    (c) 2020 Microchip Technology Inc. and its subsidiaries. You may use this
    software and any derivatives exclusively with Microchip products.

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
    IN NO EVENT WILL MICROCHIP BE LIABLE FOR ANY INDIRECT, SPECIAL, PUNITIVE,
    INCIDENTAL OR CONSEQUENTIAL LOSS, DAMAGE, COST OR EXPENSE OF ANY KIND
    WHATSOEVER RELATED TO THE SOFTWARE, HOWEVER CAUSED, EVEN IF MICROCHIP HAS
    BEEN ADVISED OF THE POSSIBILITY OR THE DAMAGES ARE FORESEEABLE. TO THE
    FULLEST EXTENT ALLOWED BY LAW, MICROCHIP'S TOTAL LIABILITY ON ALL CLAIMS IN
    ANY WAY RELATED TO THIS SOFTWARE WILL NOT EXCEED THE AMOUNT OF FEES, IF ANY,
    THAT YOU HAVE PAID DIRECTLY TO MICROCHIP FOR THIS SOFTWARE.

    MICROCHIP PROVIDES THIS SOFTWARE CONDITIONALLY UPON YOUR ACCEPTANCE OF THESE
    TERMS.
*/

/**
  Section: Included Files
*/
#include "mcc_generated_files/system.h"

/*
                         Main application
 */
int main(void)
{
    // initialize the device
    SYSTEM_Initialize();
    while (1)
    {
        // Add your application code
    }
    return 1; 
}
/**
 End of File
*/

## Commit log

2021-02-10 Schematic update 1
    [PIC32DevKit v1.0.xlsx]
2021-02-18 Schematic update 2
2021-02-18 Schematic update 3
2021-02-19 Schematic update 4
2021-02-22 Schematic update 5
2021-03-11 Schematic update 6
2021-04-08 Schematic update 7
2021-06-22 Schematic update 8
2021-07-07 Schematic update 9
2021-07-12 Schematic update 10
2021-07-15 Schematic update 11
2021-07-26 Schematic update 12
2021-07-27 Schematic update 13
2021-07-27 Schematic update 14
2021-07-28 Schematic update 15
2021-07-29 Schematic update 16
2021-07-30 Schematic update 17
2021-08-01 Schematic update 18
2021-08-03 Layout update 1
    [PIC32DevKit v1.0.xlsx]
2021-08-04 Layout update 2
    [PIC32DevKit_v1.0 - CADCAM Bottom Copper.GBR, PIC32DevKit_v1.0 - CADCAM Bottom Solder Resist.GBR, PIC32DevKit_v1.0 - CADCAM Drill.DRL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]
2021-08-10 update BoM list
    [PIC32DevKit v1.0.xlsx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]
2022-01-19 Schematic v2.0
2022-01-30 Layout v2.0
    [PIC32DevKit v2.0 Pin Maps.xlsx]
2022-02-08 Production files v2.0
    [PIC32DevKit - CADCAM Bottom Copper.GBR, PIC32DevKit - CADCAM Bottom Solder Resist.GBR, PIC32DevKit - CADCAM Drill.DRL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]
2022-03-07 Production files v2.0: BoM list
    [PIC32DevKit.xlsx]
2022-03-08 Production files v2.0: BoM list update
    [PIC32DevKit.xlsx]
2023-02-06 PIC32DevKit mini: schematic
2023-05-31 Schematic v3.0: USB C PD, power smart switching
